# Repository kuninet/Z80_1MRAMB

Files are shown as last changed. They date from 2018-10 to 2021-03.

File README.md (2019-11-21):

# Z80 128kB メモリーボード (KZ80-1MSRAM)

- 詳しい解説は以下のwikiページをご覧ください。

https://github.com/kuninet/Z80_1MRAMB/wiki

## 概要

- SBC8080ルーズキットバスにつながる128kBバンクメモリーボードです。
  - REV1 : 16kB ROM + 16kB固定RAM + 32kB 3バンクメモリー
  - REV2 ; 上記に加えて 64kBフルRAMモード装備
  - REV3 : ROM 32kジャンパ装備。アドレスデコード改良

## 機械語モニタ+TinyBASICについて

- [SBC8080データパック](http://www.amy.hi-ho.ne.jp/officetetsu/storage/sbc8080_datapack.zip)の機械語モニタ+TinyBASICを使用する場合、使用しているRAM領域(8000h〜FFFFh)をバンク切り替えする仕様となっているためRAMアドレス等を変更する必要があります。
  - [MON-TB](MON-TB/)ディレクトリにアドレス変更等を対応したソース/ROM焼き用のHEXファイルを添付しました。
  - https://github.com/kuninet/Z80_1MRAMB/tree/master/MON-TB

## ライセンス

- 本リポジトリのデータは MIT License のもとで公開します。[LICENSE.txt](LICENSE.txt)を参照して下さい。

## 参考リンク

- [SBC8080バスにつながる128kBメモリーボード(1)](https://kuninet.org/2018/08/11/sbc8080バスにつながる128kbメモリーボード1/)
- [SBC8080バスにつながる128kBメモリーボード(2)](https://kuninet.org/2018/08/12/sbc8080バスにつながる128kbメモリーボード2/)
- [SBC8080バスにつながる128kBメモリーボード(3)](https://kuninet.org/2018/08/13/sbc8080バスにつながる128kbメモリーボード3/)
  - 【注意】上記のBLOGの試作記事ではI/Oアドレスを40hにしていますが、当基板(REV1、1.1)では80hへ変更しています。
  
- KZ80-1MSRAM Rev.1 リリース0.9
  - [https://kuninet.org/2018/10/21/kz80-1msram-rev-1-%e3%83%aa%e3%83%aa%e3%83%bc%e3%82%b90-9/](https://kuninet.wordpress.com/2018/10/21/kz80-1msram-rev-1-%e3%83%aa%e3%83%aa%e3%83%bc%e3%82%b90-9/)
- KZ80/SBC80系 128kBメモリーボード REV2
  - [https://kuninet.org/2018/12/28/kz80-sbc80%e7%b3%bb-128kb%e3%83%a1%e3%83%a2%e3%83%aa%e3%83%bc%e3%83%9c%e3%83%bc%e3%83%89-rev2/](https://kuninet.wordpress.com/2018/12/28/kz80-sbc80%e7%b3%bb-128kb%e3%83%a1%e3%83%a2%e3%83%aa%e3%83%bc%e3%83%9c%e3%83%bc%e3%83%89-rev2/)

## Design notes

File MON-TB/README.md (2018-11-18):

# 機械語モニタ+TinyBASIC　(for KZ80-1MSRAM : 128kBバンクメモリー対応)

## オリジナルソースの所在

- 本ソースは、[SBC8080データパック](http://www.amy.hi-ho.ne.jp/officetetsu/storage/sbc8080_datapack.zip)に同梱されている PTBEXSA.ASM に変更を加えたものです。

## 修正点

- ワーク用メモリー領域を 固定メモリー域アドレス(4000h〜7FFFh)へ変更

```
　　FTOP	EQU	4000H
　　LTOP	EQU	5000H
　　VTOP	EQU	07000H
　　STACK	EQU	07E00H
```
- 機械語モニタのRAM開始アドレスーを変更

```
CC1:
main:
	LXI	H,-484
	DAD	SP
	SPHL
	LXI	H,482
	DAD	SP
	XCHG;;
	LXI	H,16384     <-- 4000hへ変更
	CALL	CCPINT
```

- バンクメモリーをバンク1へ初期セット

```
	ORG	ITOP
ENTRY:
;-- BANK MEM SET
	MVI	A,01H
	OUT	80H
;
```

- おまけ : Z80割り込みモード1で動作させたい場合
  - Z80割り込みモード1(割り込みがあったら強制的にRST 38hを実行)で使用したい場合はコメントアウトを外して再コンパイルしてください。

```
;
;	SYSTEM INITIALIZE
SYSINI:
	LXI	SP,STACK
;	DB	0EDH,056H   <-- コメントアウトを外すと Z80 割り込みモード1で動作します
	MVI	A,11H
```

- 上記修正によりメモリーマップは以下のようになります。

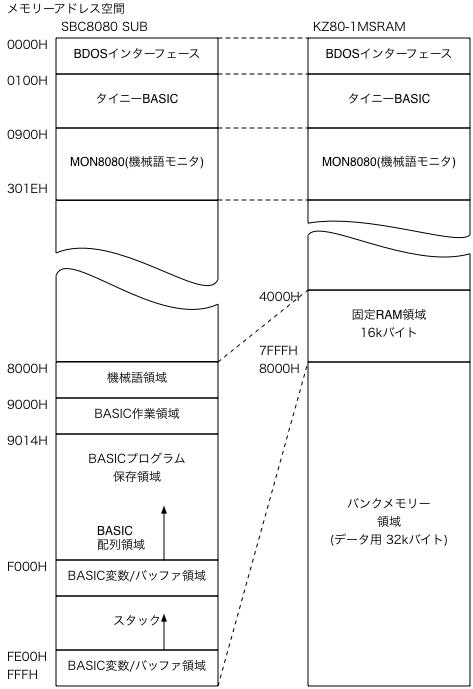
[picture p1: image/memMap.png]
メモリーマップ


## 使い方

- KZ80-1MSRAMボードで使用する場合は、HEXファイル(PTBEXS1M.HEX)を28C256(EEPROM)へ焼いてご使用ください。
- ソースを修正して再アセンブリしたい場合は、CP/MエミュレーターでMAC.COMを使ってアセンブリしてください。

  - 再アセンブリ例
```
C:\wk>\cpm32_04\cpm MAC PTBEXS1M.ASM
CP/M MACRO ASSEM 2.0
7F04
024H USE FACTOR
END OF ASSEMBLY

C:\wk>
```

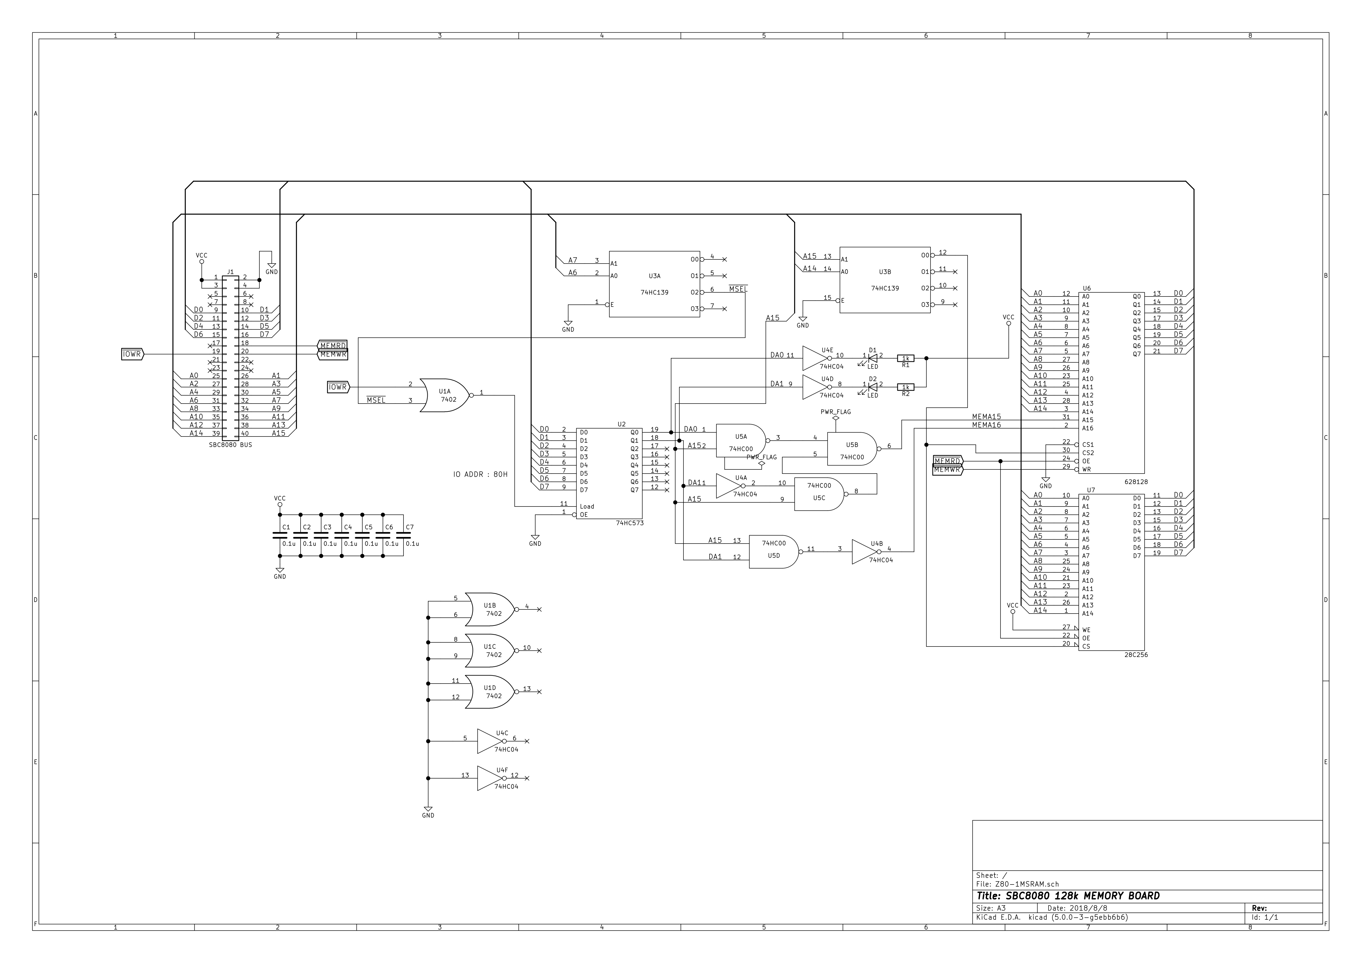
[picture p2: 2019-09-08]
image/Z80-1MSRAM-REV1.jpg

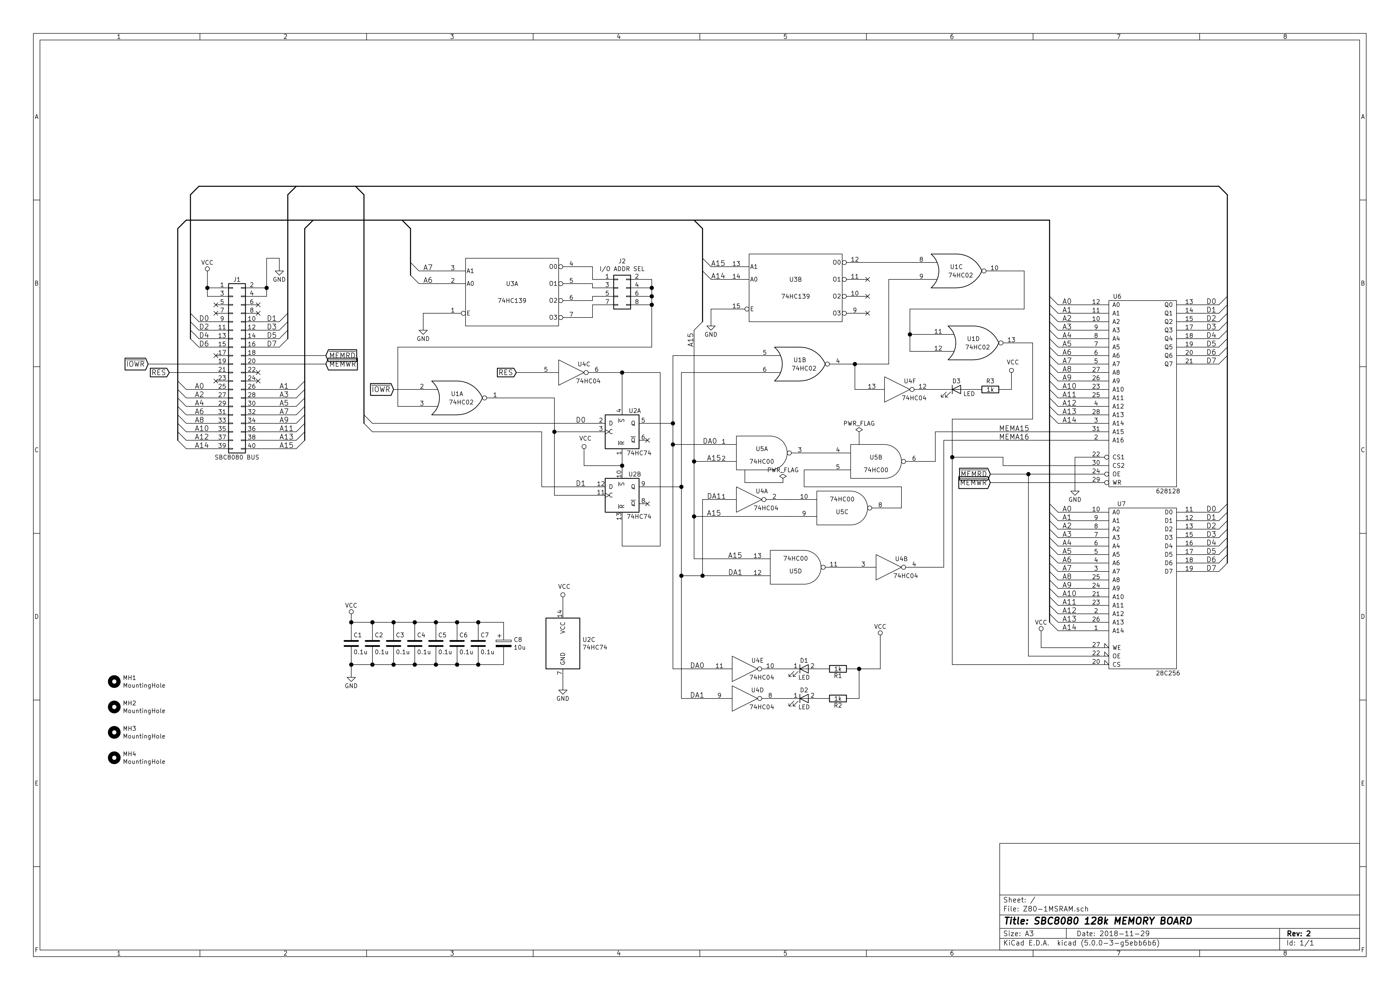
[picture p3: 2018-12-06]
image/Z80-1MSRAM-REV2.jpg

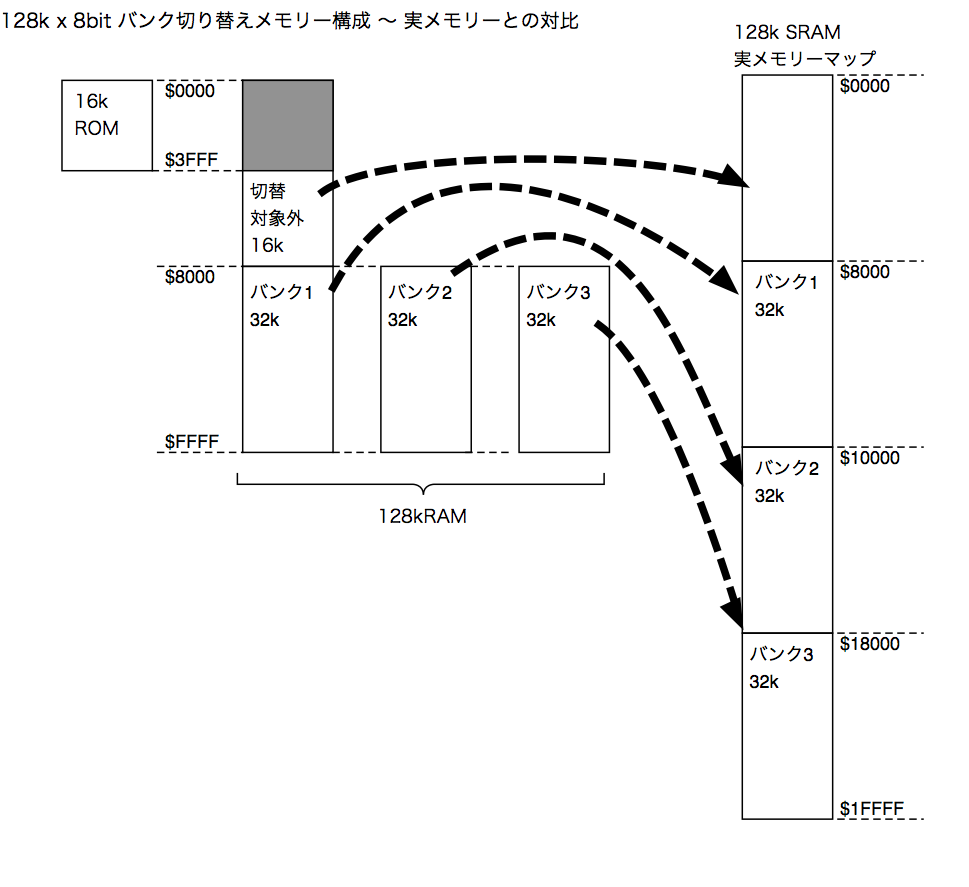
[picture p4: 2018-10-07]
image/mem-image.png

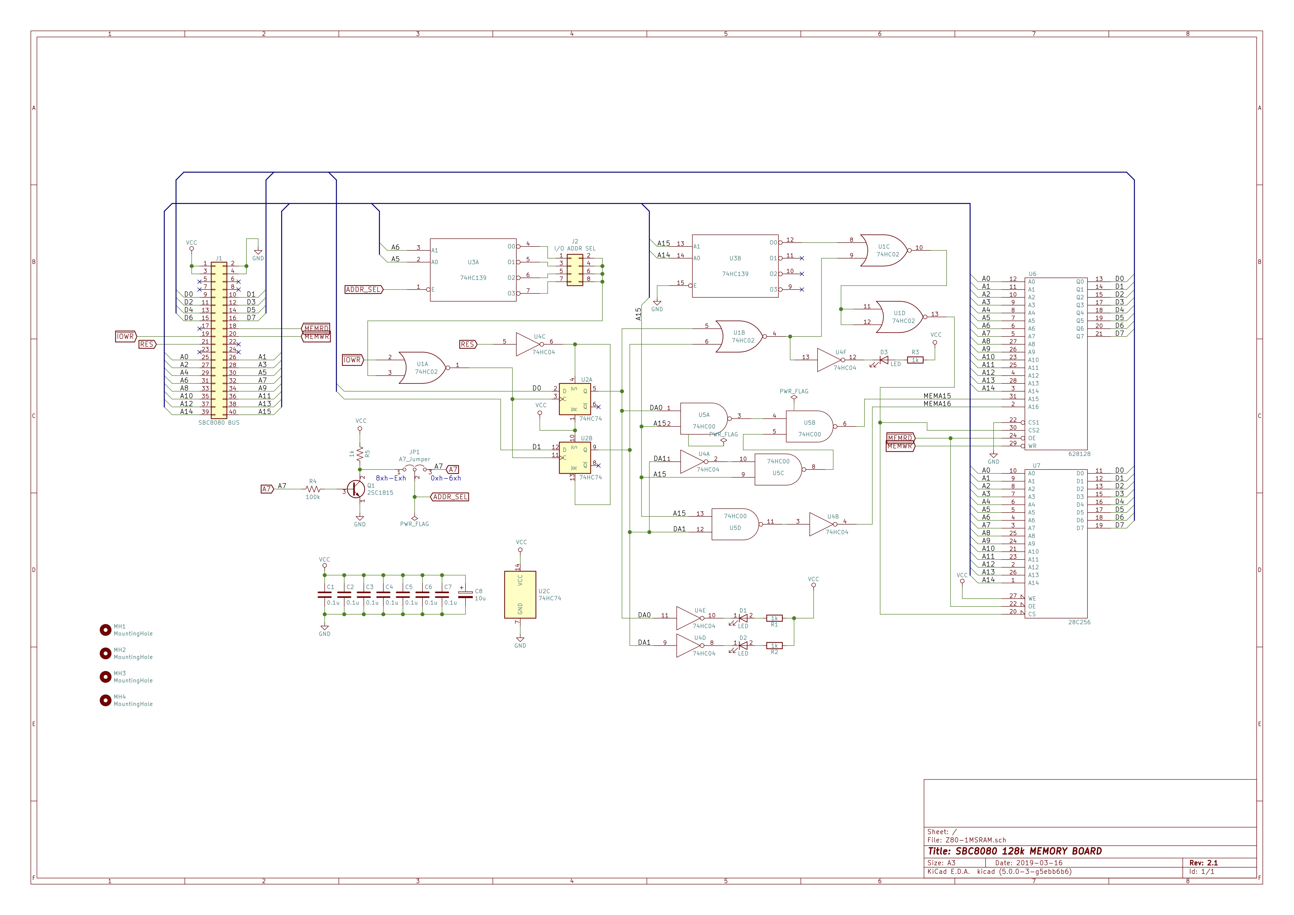
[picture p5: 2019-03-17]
image/Z80-1MSRAM-REV2-1.jpg

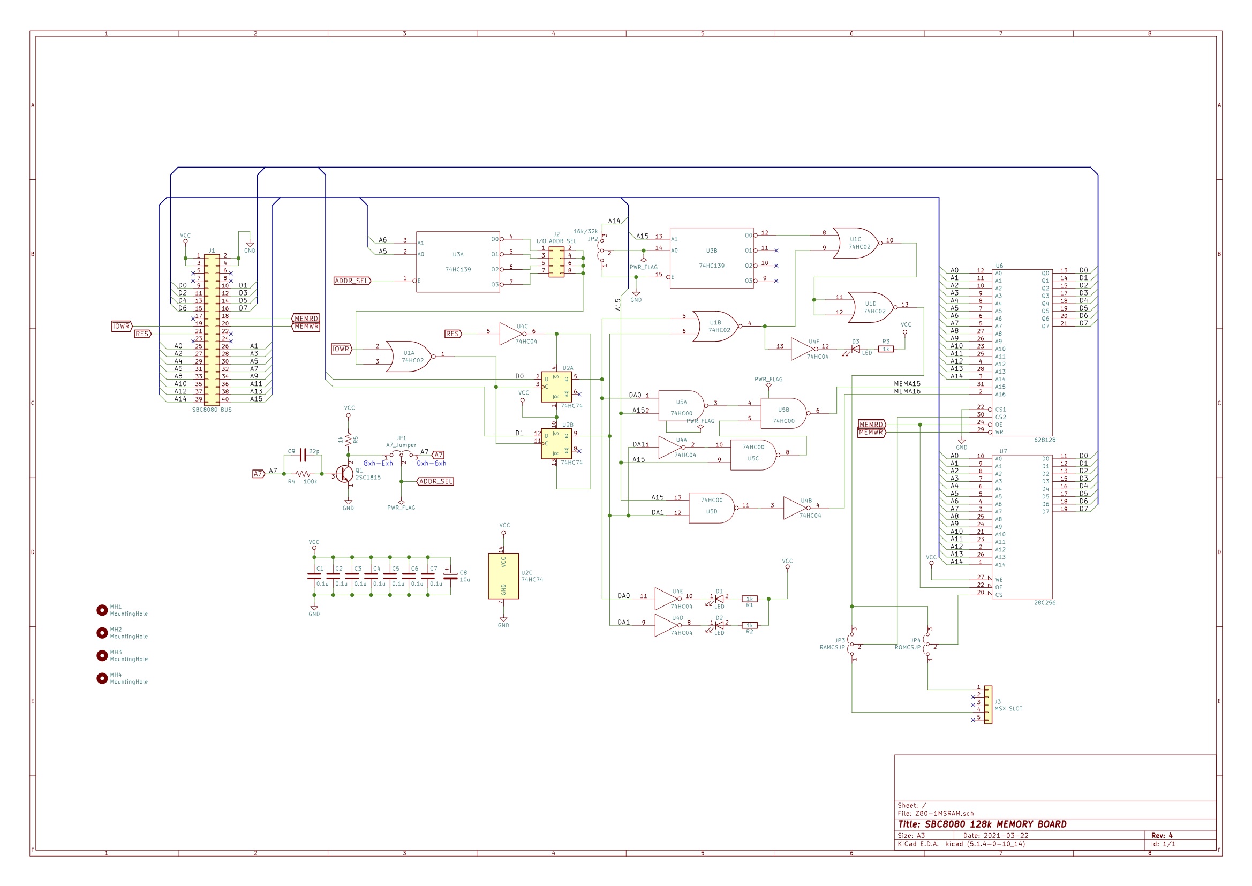
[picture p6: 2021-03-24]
image/Z80-1MSRAM-REV4.jpg

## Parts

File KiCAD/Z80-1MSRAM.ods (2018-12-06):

部品番号 | 仕様 | 数量 | 代替可能品 | 備考 | Footprint
U1 | 74HC02 | 1 | 74HCT02 |  | Housings_DIP:DIP-14_W7.62mm_Socket
U2 | 74HC74 | 1 | 74HCT74 |  | Housings_DIP:DIP-14_W7.62mm_Socket
U3 | 74HC139 | 1 | 74HCT139 |  | Housings_DIP:DIP-16_W7.62mm_Socket
U4 | 74HC04 | 1 | 74HCT04 |  | Housings_DIP:DIP-14_W7.62mm_Socket
U5 | 74HC00 | 1 | 74HCT00 |  | Housings_DIP:DIP-14_W7.62mm_Socket
U6 | HM628128ALP-7 | 1 | 128kB SRAM | ☆ピンアサインに注意。同等品を確認してください。 | Housings_DIP:DIP-32_W15.24mm_Socket
U7 | ATC28C256 | 1 | 32kB EEPROM | 16kB分のみ使用します | Housings_DIP:DIP-28_W15.24mm_Socket
D1、D2、D3 | LED | 2 | LED |  | LEDs:LED-3MM
R1、R2、R3 | 1kΩ | 2 | カーボン抵抗器 |  | Resistors_THT:R_Axial_DIN0207_L6.3mm_D2.5mm_P10.16mm_Horizontal
J1 | HIF3FC-40PA-2.54DS | 1 | 40 ピン L 型ボックスヘッダ |  | Pin_Headers:Pin_Header_Angled_2x20
C1〜C7 | 0.1uF | 7 | 積層セラミックコンデンサ |  | Capacitors_THT:C_Rect_L4.0mm_W2.5mm_P2.50mm
C8 | 10uF | 1 | 電解/タンタルコンデンサ |  | Capacitor_THT:CP_Radial_D5.0mm_P2.50mm

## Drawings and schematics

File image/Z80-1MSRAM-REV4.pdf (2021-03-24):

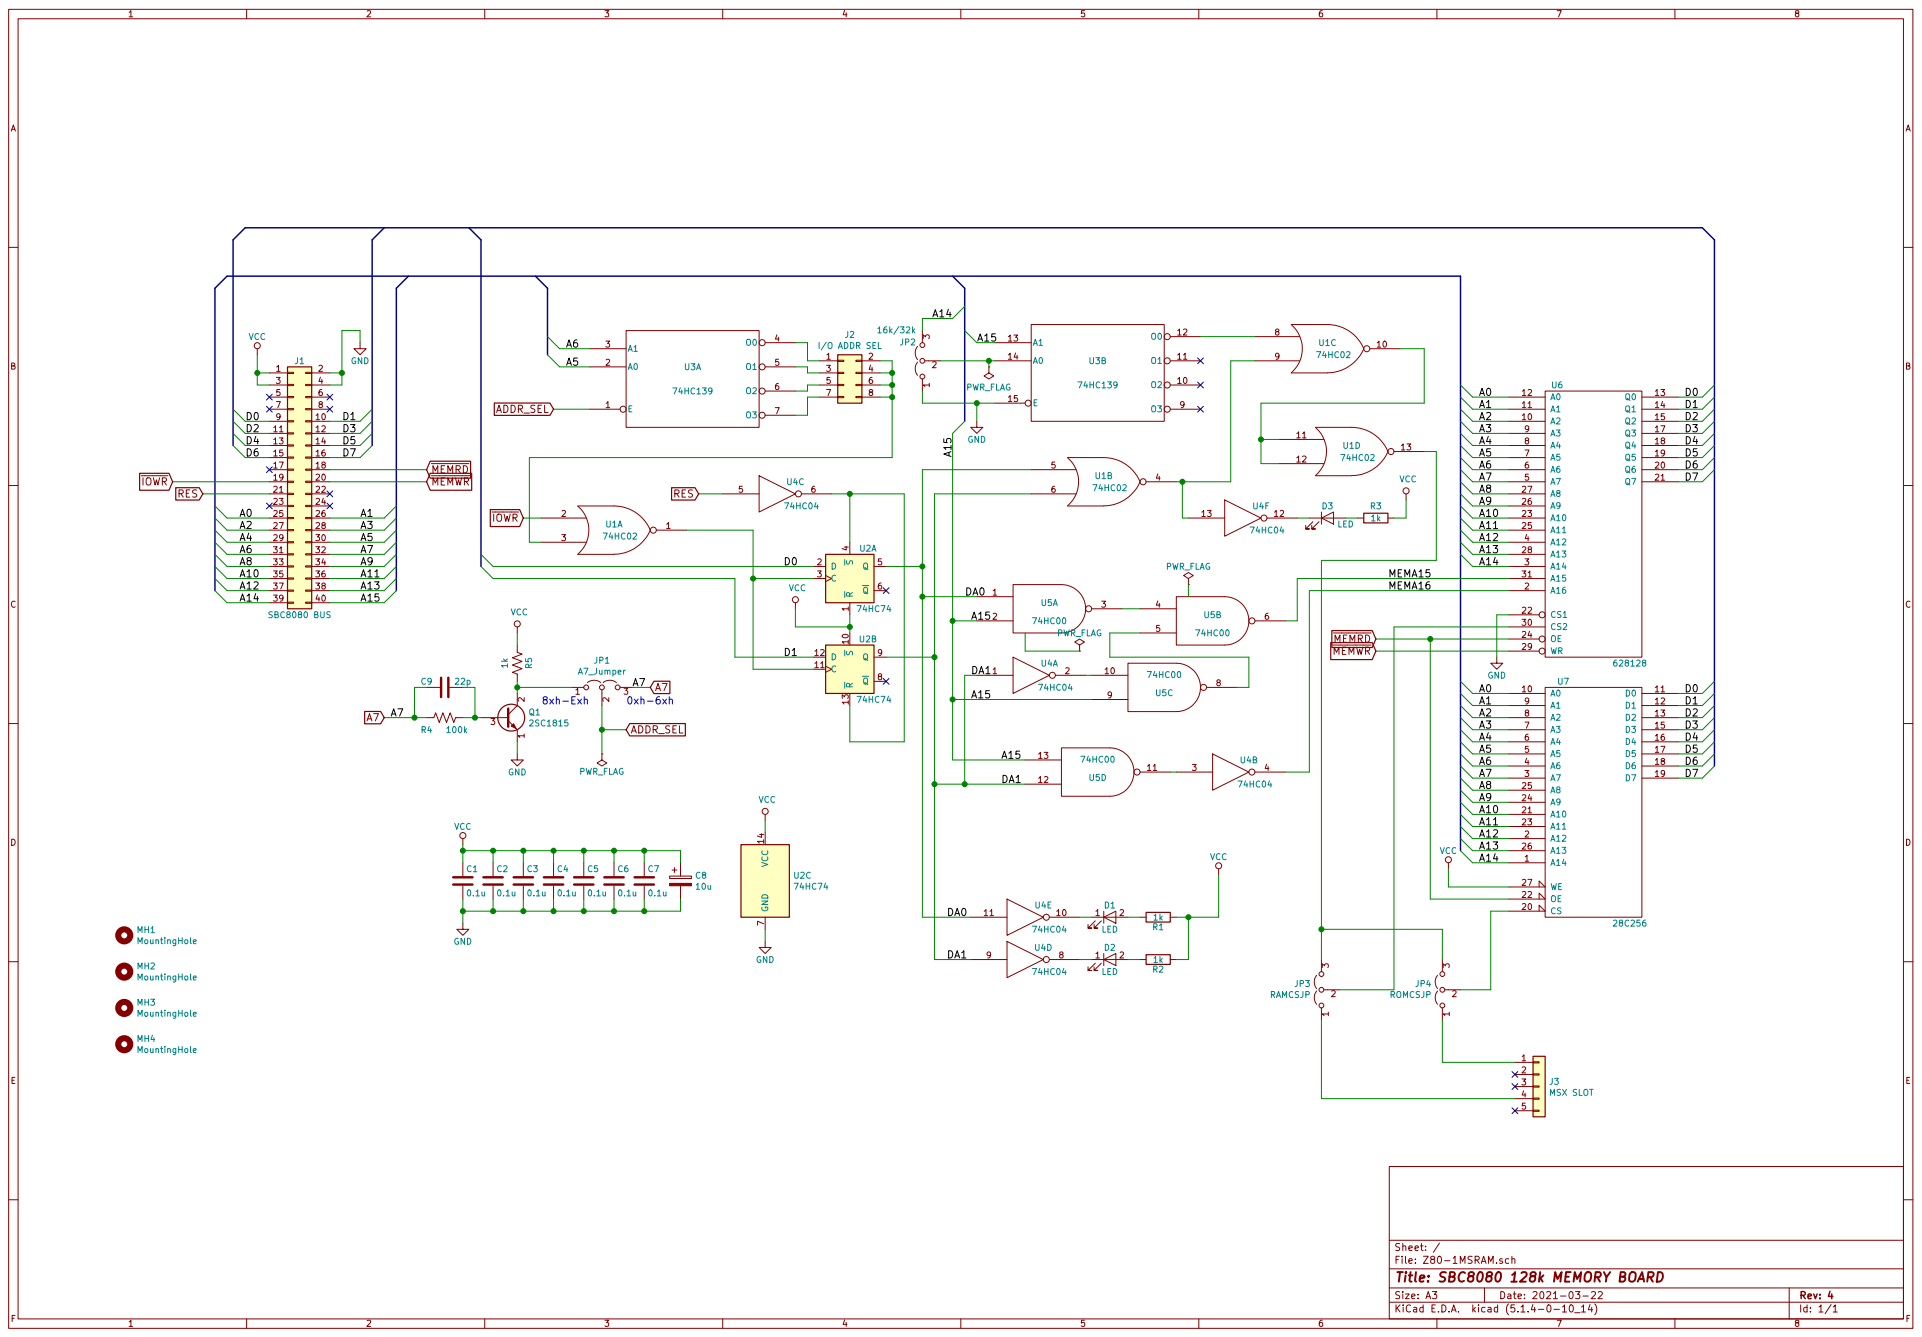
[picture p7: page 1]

File: Z80-1MSRAM.sch Sheet: / MH1 MountingHole

Id: 1/1 Title: SBC8080 128k MEMORY BOARD

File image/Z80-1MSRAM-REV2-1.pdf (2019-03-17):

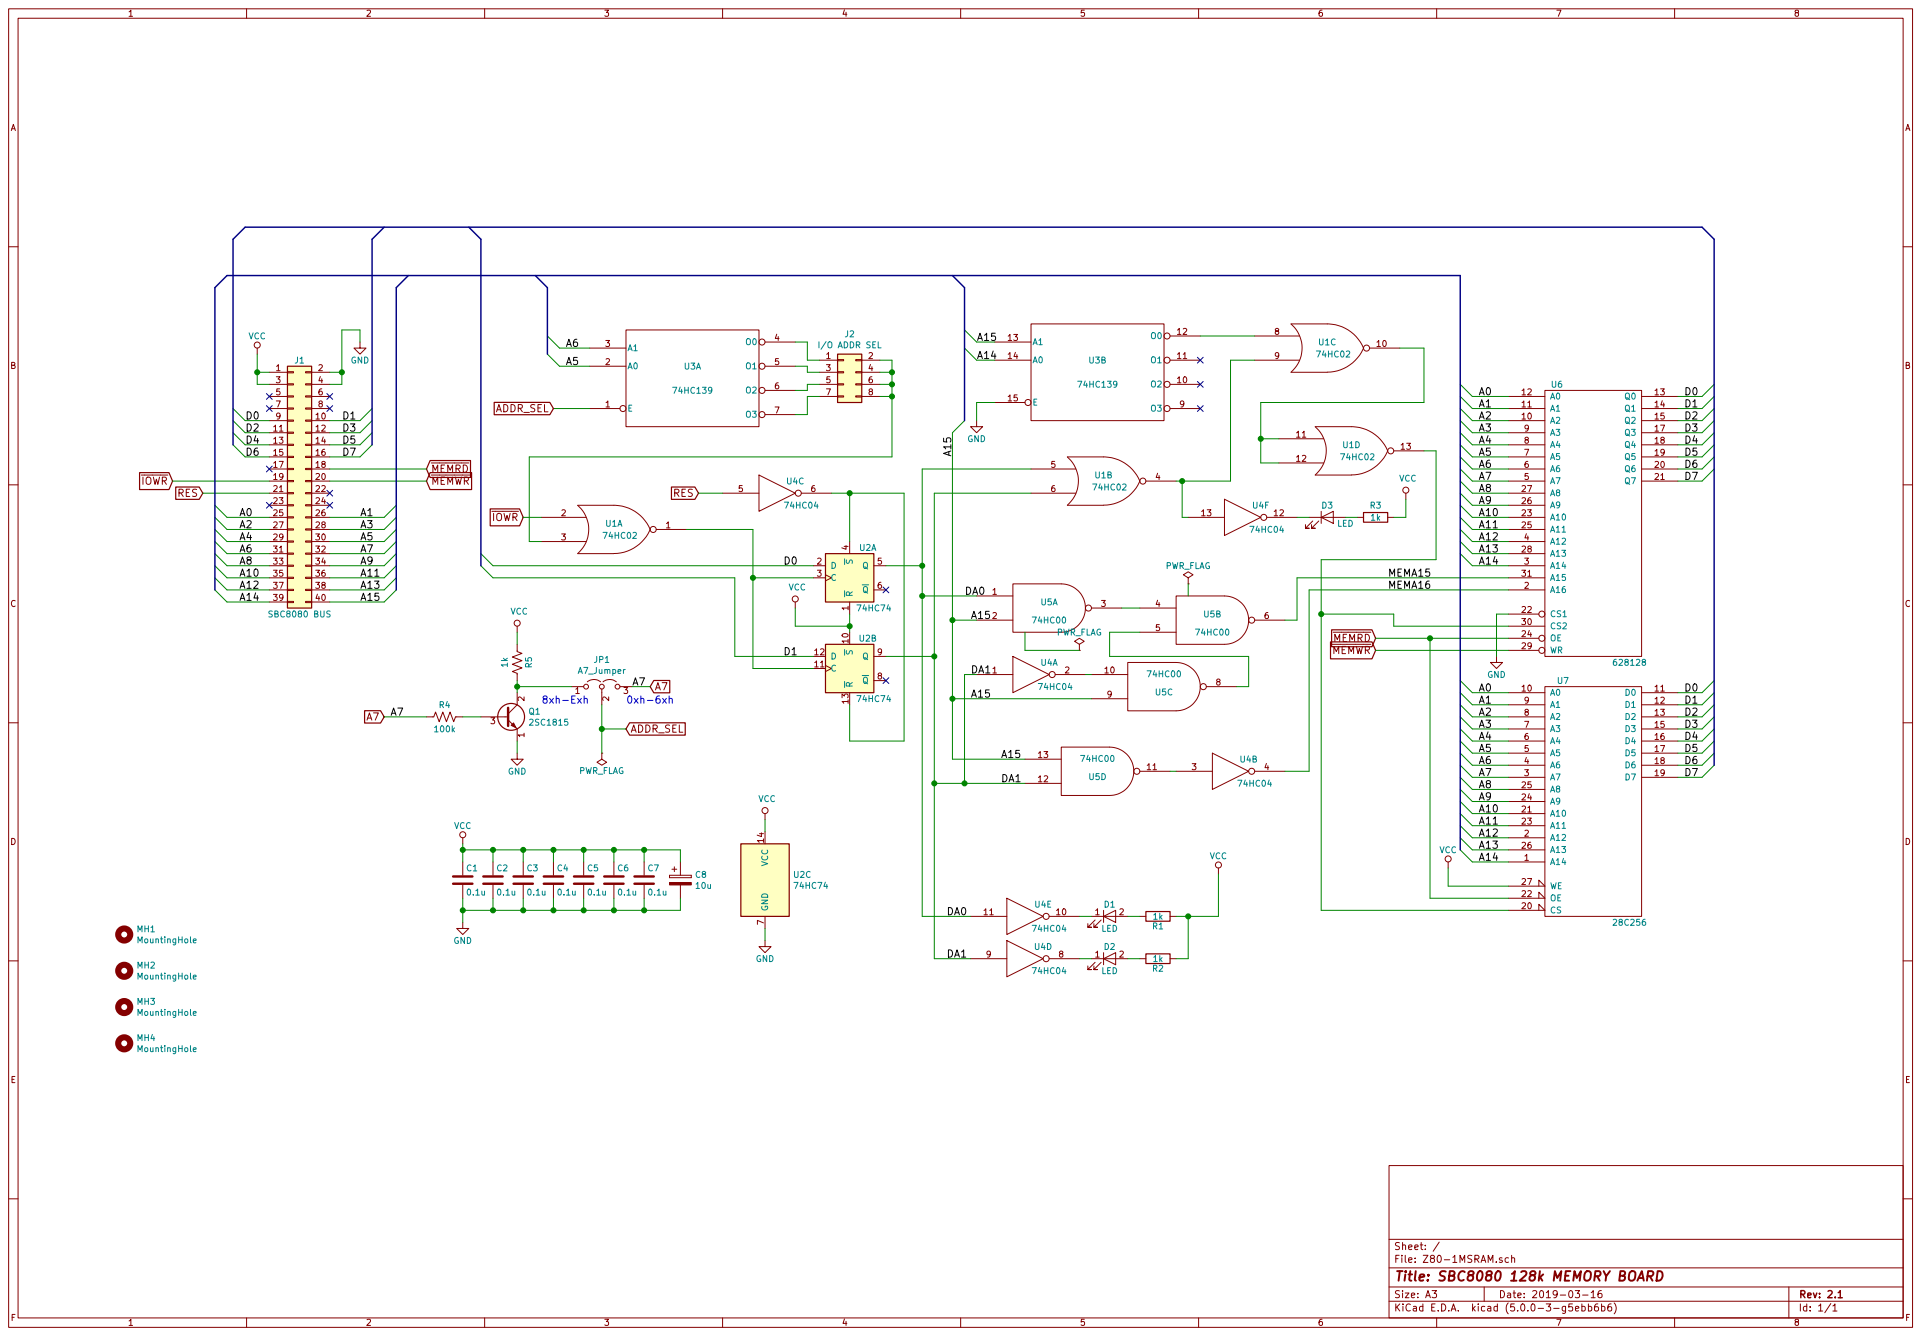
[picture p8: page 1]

10u MH1 MountingHole MH2 MountingHole MH3 MountingHole MH4 MountingHole

File: Z80-1MSRAM.sch Sheet: /
Id: 1/1 Title: SBC8080 128k MEMORY BOARD

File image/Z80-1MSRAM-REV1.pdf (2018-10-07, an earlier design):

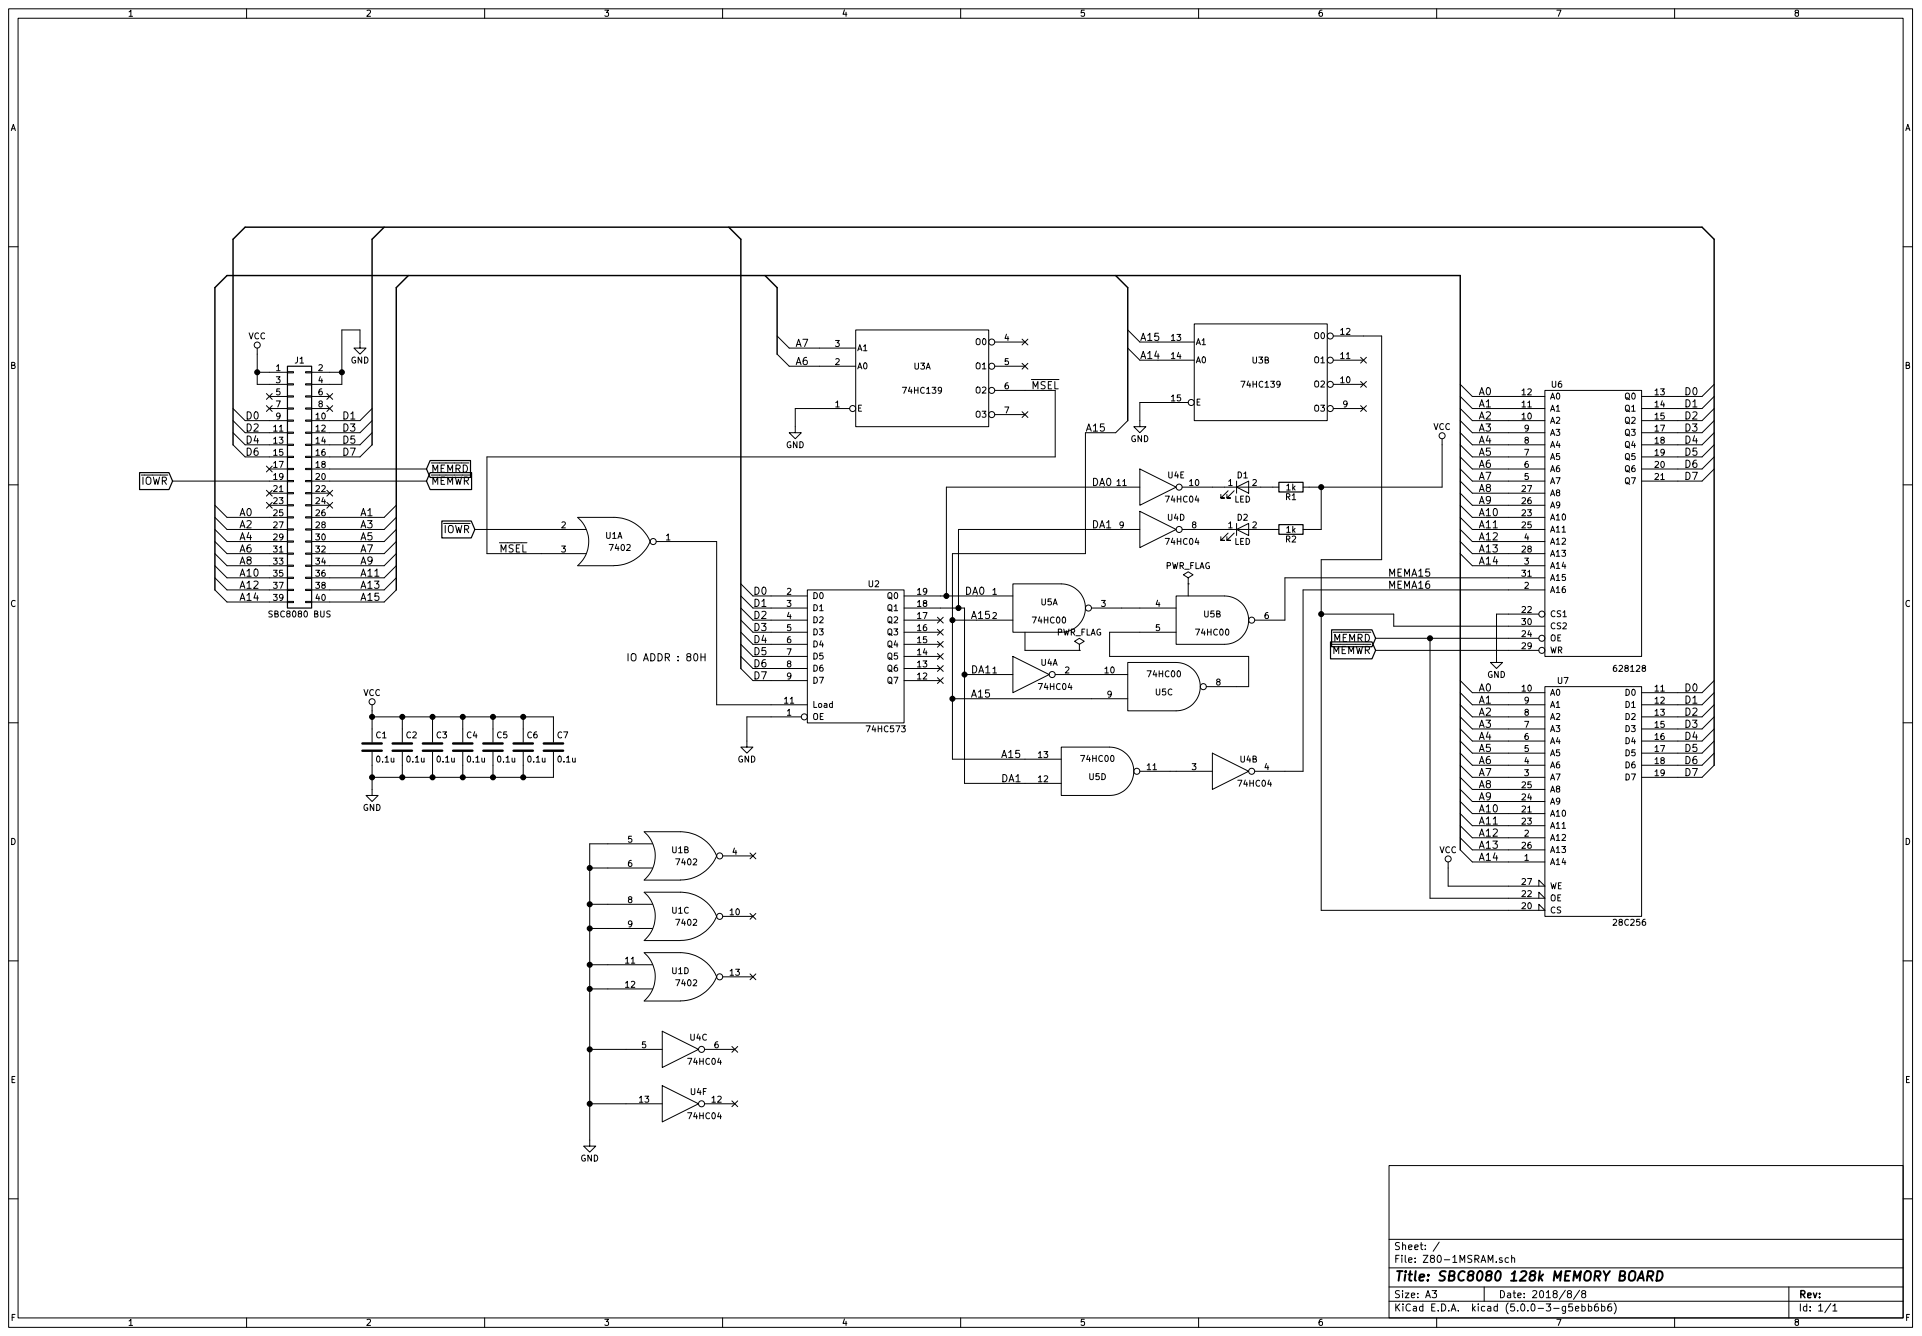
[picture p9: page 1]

File: Z80-1MSRAM.sch Sheet: /
Id: 1/1 Title: SBC8080 128k MEMORY BOARD

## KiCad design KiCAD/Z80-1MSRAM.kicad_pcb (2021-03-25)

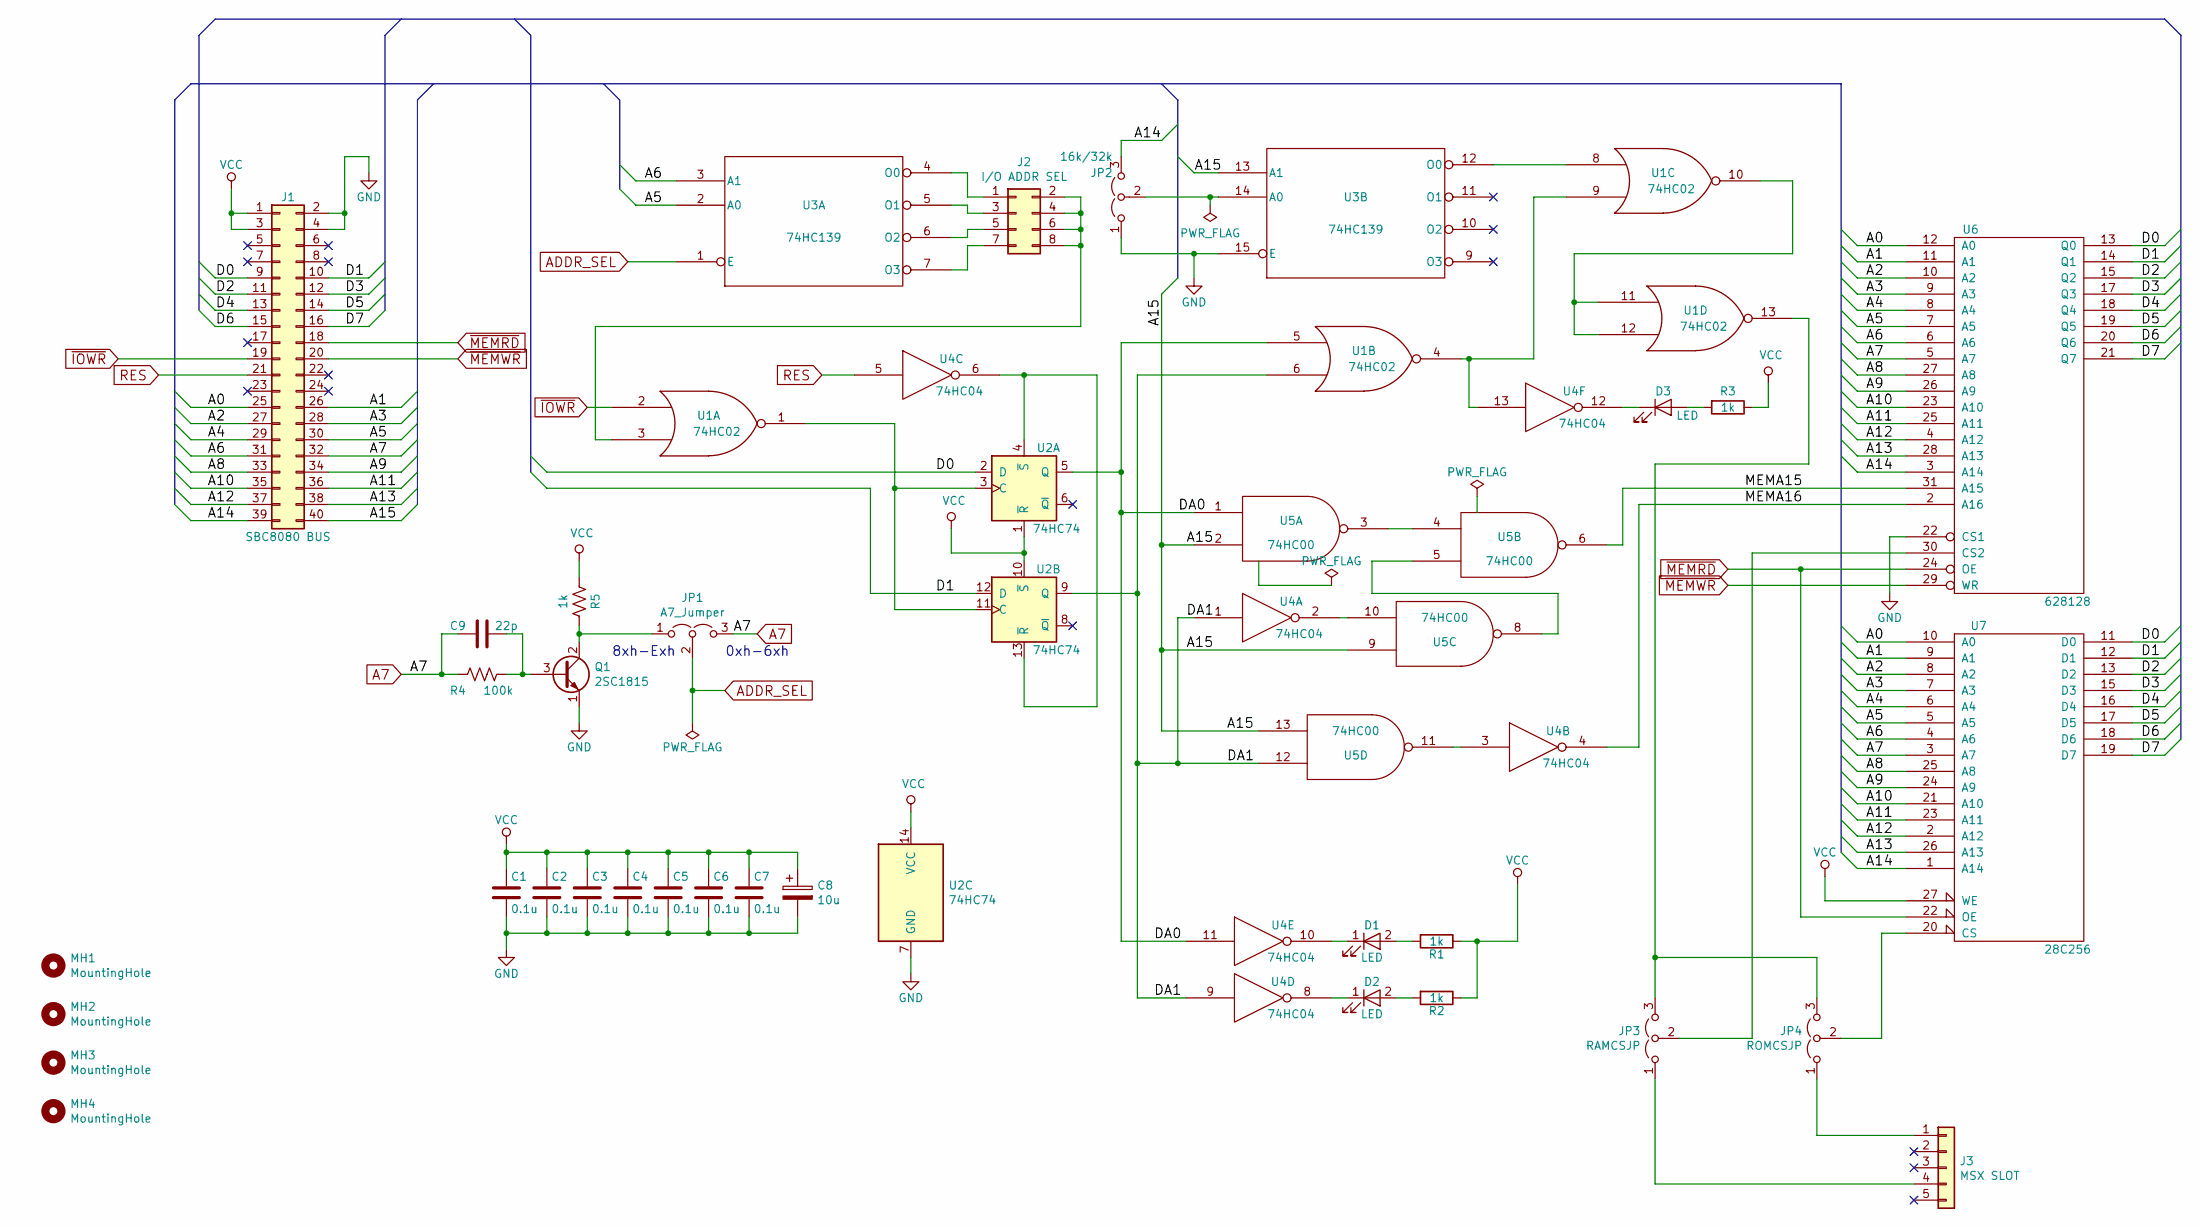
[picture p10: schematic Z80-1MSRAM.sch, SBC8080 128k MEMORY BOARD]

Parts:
C1, C2, C3, C4, C5, C6, C7: 0.1u; C_Rect_L4.0mm_W2.5mm_P2.50mm
C8: 10u; CP_Radial_D5.0mm_P2.50mm
C9: 22p; C_Disc_D3.0mm_W1.6mm_P2.50mm
D1, D2: LED; LED-3MM
D3: LED; LED_D3.0mm
J1: SBC8080 BUS; Pin_Header_Angled_2x20
J2: I/O ADDR SEL; PinHeader_2x04_P2.54mm_Vertical
J3: MSX SLOT; PinHeader_1x05_P2.54mm_Vertical
JP1: A7_Jumper; PinHeader_1x03_P2.54mm_Vertical
JP2: 16k/32k; PinHeader_1x03_P2.54mm_Vertical
JP3: RAMCSJP; PinHeader_1x03_P2.54mm_Vertical
JP4: ROMCSJP; PinHeader_1x03_P2.54mm_Vertical
MH1, MH2, MH3, MH4: MountingHole; MountingHole_3.2mm_M3
Q1: 2SC1815; TO-92L_Inline_Wide
R1, R2, R3, R5: 1k; R_Axial_DIN0207_L6.3mm_D2.5mm_P10.16mm_Horizontal
R4: 100k; R_Axial_DIN0207_L6.3mm_D2.5mm_P10.16mm_Horizontal
U1: 74HC02; DIP-14_W7.62mm_Socket
U2: 74HC74; DIP-14_W7.62mm_Socket
U3: 74HC139; DIP-16_W7.62mm_Socket
U4: 74HC04; DIP-14_W7.62mm_Socket
U5: 74HC00; DIP-14_W7.62mm_Socket
U6: 628128; DIP-32_W15.24mm_Socket
U7: 28C256; DIP-28_W15.24mm_Socket

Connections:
/A0: J1.25, U6.12 (A0), U7.10 (A0)
/A1: J1.26, U6.11 (A1), U7.9 (A1)
/A2: J1.27, U6.10 (A2), U7.8 (A2)
/A3: J1.28, U6.9 (A3), U7.7 (A3)
/A4: J1.29, U6.8 (A4), U7.6 (A4)
/A5: J1.30, U3.2 (A0), U6.7 (A5), U7.5 (A5)
/A6: J1.31, U3.3 (A1), U6.6 (A6), U7.4 (A6)
/A8: J1.33, U6.27 (A8), U7.25 (A8)
/A9: J1.34, U6.26 (A9), U7.24 (A9)
/A10: J1.35, U6.23 (A10), U7.21 (A10)
/A11: J1.36, U6.25 (A11), U7.23 (A11)
/A12: J1.37, U6.4 (A12), U7.2 (A12)
/A13: J1.38, U6.28 (A13), U7.26 (A13)
/A14: J1.39, JP2.3 (B), U6.3 (A14), U7.1 (A14)
/A15: J1.40, U3.13 (A1), U5.2, U5.9, U5.13
/D0: J1.9, U2.2 (D), U6.13 (Q0), U7.11 (D0)
/D1: J1.10, U2.12 (D), U6.14 (Q1), U7.12 (D1)
/D2: J1.11, U6.15 (Q2), U7.13 (D2)
/D3: J1.12, U6.17 (Q3), U7.15 (D3)
/D4: J1.13, U6.18 (Q4), U7.16 (D4)
/D5: J1.14, U6.19 (Q5), U7.17 (D5)
/D6: J1.15, U6.20 (Q6), U7.18 (D6)
/D7: J1.16, U6.21 (Q7), U7.19 (D7)
/DA0: U1.5, U2.5 (Q), U4.11, U5.1
/DA1: U1.6, U2.9 (Q), U4.1, U4.9, U5.12
/MEMA15: U5.6, U6.31 (A15)
/MEMA16: U4.4, U6.2 (A16)
A7: C9.2, J1.32, JP1.3 (B), R4.2, U6.5 (A7), U7.3 (A7)
ADDR_SEL: JP1.2 (C), U3.1 (E)
GND: C1.2, C2.2, C3.2, C4.2, C5.2, C6.2, C7.2, C8.2, J1.2, J1.4, JP2.1 (A), Q1.1 (E), U1.7 (GND), U2.7 (GND), U3.8 (GND), U3.15 (E), U4.7 (GND), U5.7 (GND), U6.16 (GND), U6.22 (CS1), U7.14 (GND)
unnamed: C9.1, Q1.3 (B), R4.1
unnamed: D1.1 (K), U4.10
unnamed: D1.2 (A), R1.2
unnamed: D2.1 (K), U4.8
unnamed: D2.2 (A), R2.2
unnamed: D3.1 (K), U4.12
unnamed: D3.2 (A), R3.2
unnamed: J2.1, U3.4 (O0)
unnamed: J2.2, J2.4, J2.6, J2.8, U1.3
unnamed: J2.3, U3.5 (O1)
unnamed: J2.5, U3.6 (O2)
unnamed: J2.7, U3.7 (O3)
unnamed: J3.1, JP4.1 (A)
unnamed: J3.4, JP3.1 (A)
unnamed: JP1.1 (A), Q1.2 (C), R5.1
unnamed: JP2.2 (C), U3.14 (A0)
unnamed: JP3.2 (C), U6.30 (CS2)
unnamed: JP3.3 (B), JP4.3 (B), U1.13
unnamed: JP4.2 (C), U7.20 (CS)
unnamed: U1.1, U2.3 (C), U2.11 (C)
unnamed: U1.4, U1.9, U4.13
unnamed: U1.8, U3.12 (O0)
unnamed: U1.10, U1.11, U1.12
unnamed: U2.4 (~S), U2.13 (~R), U4.6
unnamed: U4.2, U5.10
unnamed: U4.3, U5.11
unnamed: U5.3, U5.4
unnamed: U5.5, U5.8
RES: J1.21, U4.5
VCC: C1.1, C2.1, C3.1, C4.1, C5.1, C6.1, C7.1, C8.1, J1.1, J1.3, R1.1, R2.1, R3.1, R5.2, U1.14 (VCC), U2.1 (~R), U2.10 (~S), U2.14 (VCC), U3.16 (VCC), U4.14 (VCC), U5.14 (VCC), U6.32 (VCC), U7.27 (WE), U7.28 (VCC)
~IOWR: J1.19, U1.2
~MEMRD: J1.18, U6.24 (OE), U7.22 (OE)
~MEMWR: J1.20, U6.29 (WR)

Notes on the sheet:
0xh-6xh
8xh-Exh

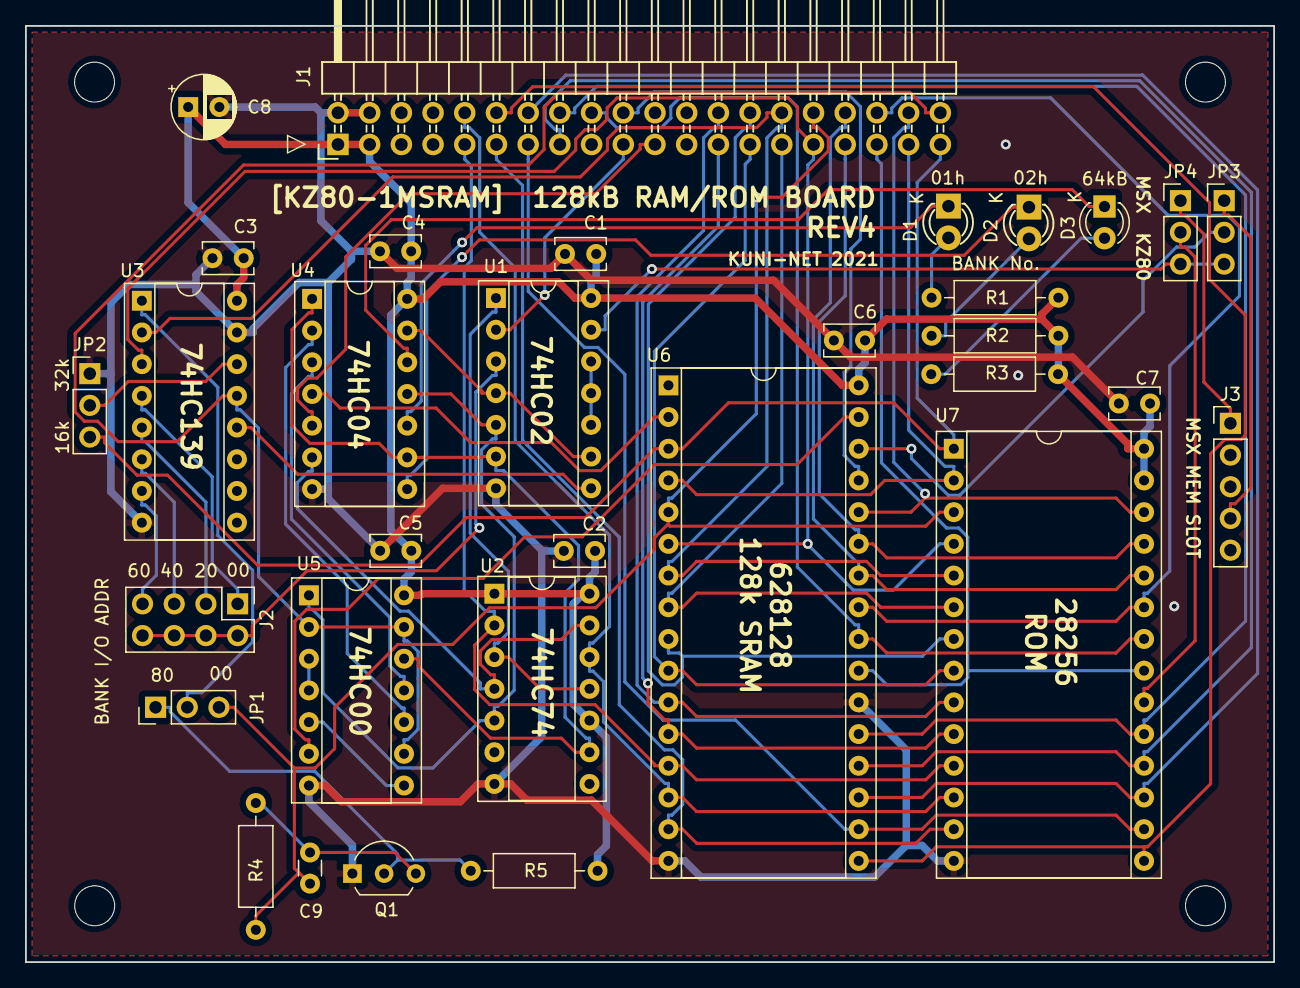
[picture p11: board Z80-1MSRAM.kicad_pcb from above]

Board: 2 copper layers, 100.0 x 75.0 mm, 36 parts (0 on the bottom side), 63 nets.

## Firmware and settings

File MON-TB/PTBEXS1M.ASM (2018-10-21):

; Small-C Version 3.01  90/06/01  < FUTURE FORUM & S.Kiyo > 
; modify for 128kRAM (KZ80-1MSRAM)
; 
ITOP	EQU	0100H
FTOP	EQU	4000H
LTOP	EQU	5000H
VTOP	EQU	07000H
STACK	EQU	07E00H
;
LBUF	EQU	VTOP+0037H
LBFSZ	EQU	80
MSTK	EQU	LBUF+LBFSZ
TMSTK	EQU	MSTK+30
;
PROMPT	EQU	'>'
RUBOUT	EQU	7FH
BS	EQU	08H
ESC	EQU	1BH
;
TST	MACRO	STR,ADRS
	CALL	TEST
	DB	STR
	DB	ADRS-$-1
	ENDM
CASE	MACRO	STR,ADRS
	DB	STR
	DB	(ADRS SHR 8)+80H
	DB	ADRS AND 0FFH
	ENDM
ENDC	MACRO	ADRS
	DB	(ADRS+8000H) SHR 8
	DB	ADRS AND 0FFH
	ENDM
;
UARTRD	EQU	00H
UARTRC	EQU	01H
;
;	BDOS VERSION 1.03
;
;
;	RESET
	ORG	0000H
	JMP	SYSINI
;
;	BDOS
	ORG	0005H
BDOS:
	PUSH	PSW
	MOV	A,C
	RLC
	ADD	C
	MOV	C,A
	POP	PSW
	MVI	B,00H
	LXI	H,JMPTBL
	DAD	B
	PCHL
JMPTBL:	JMP	SYSINI
	JMP	RBUFRD
	JMP	USRTWT
	JMP	RBUFRD
	JMP	USRTWT
	JMP	USRTWT
	JMP	DCONIO
;
;	8251 -> A
USRTRD:
	IN	UARTRC
	ANI	00000010B
	JZ	USRTRD
	IN	UARTRD
	RET
;
;	RST7
	ORG	0038H
INTRCV:
	DI
	PUSH	PSW
	PUSH	B
	PUSH	D
	PUSH	H
	CALL	USRTRD
	CPI	11H
	JZ	STRWT1
	CPI	13H
	JNZ	STRWT2
STRWT1:	STA	XFLAGS
	JMP	RWTEXT
STRWT2:	MOV	D,A
	LDA	RBFCNT
	CPI	0FFH
	JZ	RWTEXT
	CPI	0FFH-80
	JNZ	STRWT3
	MVI	E,13H
	CALL	USRTWT
STRWT3:	INR	A
	STA	RBFCNT
	LDA	RBFWTP
	MOV	C,A
	MVI	B,00H
	LXI	H,RECBUF
	DAD	B
	MOV	M,D
	INR	A
	STA	RBFWTP
RWTEXT:	POP	H
	POP	D
	POP	B
	POP	PSW
	EI
	RET
;
;	BUFER -> A
RBUFRD:
	PUSH	B
	PUSH	D
	PUSH	H
LOPRBR:	LDA	RBFCNT
	CPI	00H
	JZ	LOPRBR
	DI
	CPI	0FFH-80
	JNZ	STRRD1
	MVI	E,11H
	CALL	USRTWT
STRRD1:	DCR	A
	STA	RBFCNT
	LDA	RBFRDP
	MOV	C,A
	MVI	B,00H
	LXI	H,RECBUF
	DAD	B
	MOV	D,M
	INR	A
	STA	RBFRDP
	MOV	A,D
	EI
	POP	H
	POP	D
	POP	B
	RET
;
;	E -> 8251
USRTWT:
	PUSH	PSW
UWLOP1:	LDA	XFLAGS
	CPI	13H
	JZ	UWLOP1
UWLOP2:	IN	UARTRC
	ANI	00000001B
	JZ	UWLOP2
	MOV	A,E
	OUT	UARTRD
	POP	PSW
	RET
;
;	DIRECT I/O
DCONIO:
	PUSH	PSW
	MOV	A,E
	CPI	0FFH
	JZ	DCONIN
	JMP	UWLOP2
DCONIN:	POP	PSW
	LDA	RBFCNT
	CPI	00H
	RZ
	JMP	RBUFRD
;
;	SYSTEM INITIALIZE
SYSINI:
	LXI	SP,STACK
;	DB	0EDH,056H
	MVI	A,11H
	STA	XFLAGS
	MVI	A,00H
	STA	RBFCNT
	STA	RBFRDP
	STA	RBFWTP
	OUT	UARTRC
	OUT	UARTRC
	OUT	UARTRC
	MVI	A,01000000B
	OUT	UARTRC
	MVI	A,01001110B
	OUT	UARTRC
	MVI	A,00110111B
	OUT	UARTRC
;
	EI
;
	JMP	ENTRY
;
	ORG	ITOP
ENTRY:
;-- BANK MEM SET
	MVI	A,01H
	OUT	80H
;
	LXI	SP,STACK
	LXI	H,OTOP
	SHLD	OBTM
	CALL	CRLF
	LXI	D,OPNMS1
	SUB	A
	CALL	MSG
	LXI	D,OPNMS2
	SUB	A
	CALL	MSG
	LXI	D,OPNMS3
	SUB	A
	CALL	MSG
;
START:
	CALL	CRLF
	LXI	D,OKMES
	SUB	A
	CALL	MSG
	LXI	H,$+7
	SHLD	CLABL
	LXI	H,0000H
	SHLD	FCNTR
	SHLD	RSTCK
;
EDITR:	MVI	A,PROMPT
	CALL	GETL
	PUSH	D
	LXI	D,LBUF
	CALL	GINT
	CALL	SKPBL
	MOV	A,H
	ORA	L
	POP	B
	JZ	KWCPR
INSRT:	DCX	D
	MOV	A,H
	STAX	D
	DCX	D
	MOV	A,L
	STAX	D
	PUSH	B
	PUSH	D
	MOV	A,C
	SUB	E
	PUSH	PSW
	CALL	SRCH
	PUSH	D
	JNZ	MOVE
	PUSH	D
	CALL	SKIPL
	POP	B
	LHLD	OBTM
	CALL	TRNSF
	MOV	H,B
	MOV	L,C
	SHLD	OBTM
MOVE:	POP	B
	LHLD	OBTM
	POP	PSW
	PUSH	H
	CPI	03H
	JZ	START
	ADD	L
	MOV	L,A
	MVI	A,00H
	ADC	H
	MOV	H,A
	LXI	D,VTOP
	CALL	COMPR
	JNC	ERSRY
	SHLD	OBTM
	POP	D
	CALL	TR2
	POP	D
	POP	H
	CALL	TRNSF
	JMP	EDITR
;
GETL:	CALL	PUT
	LXI	D,LBUF
GETL1:	CALL	GET
	JZ	GETL1
	CPI	0AH
	JZ	GETL1
	ORA	A
	JZ	GETL1
	CPI	BS
	JZ	CRUB
	CPI	'X'-'@'
	JZ	CCAN
	CALL	PUT
	STAX	D
	INX	D
	CPI	0DH
	RZ
	MOV	A,E
	CPI	LBUFL + LBFSZ
	JNZ	GETL1
CRUB:	MOV	A,E
	CPI	LBUFL
	JZ	GETL1
	DCX	D
	MVI	A,BS
	CALL	PUT
	JMP	GETL1
CCAN:	CALL	CRLF
	MVI	A,'@'
	JMP	GETL
LBUFL	EQU	LBUF AND 0FFH
;
SRCH:	MOV	A,H
	ORA	A
	JM	ERHOW
	LXI	D,OTOP
SRCH1:	PUSH	H
	LHLD	OBTM
	DCX	H
	CALL	COMPR
	POP	H
	RC
	LDAX	D
	SUB	L
	MOV	B,A
	INX	D
	LDAX	D
	SBB	H
	JC	SKPL1
	DCX	D
	ORA	B
	RET
;
SKIPL:	INX	D
SKPL1:	INX	D
SKPL2:	LDAX	D
	CPI	0DH
	JNZ	SKPL1
	INX	D
	JMP	SRCH1
;
TRNSF:	CALL	COMPR
	RZ
	LDAX	D
	STAX	B
	INX	D
	INX	B
	JMP	TRNSF
;
TR2:	MOV	A,B
	SUB	D
	JNZ	TR2E
	MOV	A,C
	SUB	E
	RZ
TR2E:	DCX	D
	DCX	H
	LDAX	D
	MOV	M,A
	JMP	TR2
;
KWCPR:	LXI	H,CMDKW-1
;
NXTKW:	CALL	SKPBL
NXTK1:	PUSH	D
KWC1:	LDAX	D
	INX	D
	CPI	'.'
	JZ	KWSRT
	INX	H
	CMP	M
	JZ	KWC1
	MVI	A,7FH
	DCX	D
	CMP	M
	JC	EXEQT
KWSK1:	INX	H
	CMP	M
	JNC	KWSK1
	INX	H
	POP	D
	JMP	NXTK1
;
KWSRT:	MVI	A,7FH
KWSK2:	INX	H
	CMP	M
	JNC	KWSK2
;
EXEQT:	MOV	A,M
	INX	H
	MOV	L,M
	ANI	7FH
	MOV	H,A
	POP	PSW
	PCHL
;
TEST:	XTHL
	CALL	SKPBL
	CMP	M
	INX	H
	JZ	TSTEQ
	PUSH	B
	MOV	C,M
	MVI	B,00H
	DAD	B
	POP	B
	DCX	D
TSTEQ:	INX	D
	INX	H
	XTHL
	RET
;
SKPBL:	LDAX	D
	CPI	' '
	RNZ
	INX	D
	JMP	SKPBL
;
CMDKW:	CASE	'LIST',LIST
	CASE	'RUN',RUN
	CASE	'NEW',NEW
	CASE	'SYSTEM',SSYSTEM
	CASE	'MON',MON
STMKW:	CASE	'NEXT',NEXT
	CASE	'LET',LET
	CASE	'INPUT',INPUT
	CASE	'IF',IFSTM
	CASE	'GOTO',GOTO
	CASE	'GOSUB',GOSUB
	CASE	'RETURN',RETRN
	CASE	'REM',REM
	CASE	'FOR',FOR
	CASE	'PRINT',PRINT
	CASE	'STOP',STOP
	CASE	'EXEC',SEXEC
	ENDC	LETDF
;
MON:	JMP	main
;
SEXEC:
	CALL	EEXPR
	PUSH	PSW
	PUSH	B
	PUSH	D
	LXI	D,EXRET
	PUSH	D
	LXI	D,FTOP
	DAD	D
	PCHL
EXRET:	POP	D
	POP	B
	POP	PSW
	JMP	ENDL
;
NEW:	CALL	TSCR2
	LXI	H,OTOP
	SHLD	OBTM
STOP:	CALL	TSCR2
	JMP	START
SSYSTEM:
	MVI	C,0
	CALL	0005H
;
GOSUB:	CALL	PSHV
	CALL	EEXPR
	PUSH	D
	CALL	SRCH
	JNZ	ERHW1
	LHLD	CLABL
	PUSH	H
	LHLD	RSTCK
	PUSH	H
	LXI	H,0000H
	SHLD	FCNTR
	DAD	SP
	SHLD	RSTCK
	JMP	RUN2
;
RETRN:	CALL	TSCR2
	LHLD	RSTCK
	MOV	A,H
	ORA	L
	JZ	ERWHT
	SPHL
	POP	H
	SHLD	RSTCK
	POP	H
	SHLD	CLABL
	POP	D
	CALL	POPV
	JMP	ENDL
;
FOR:	CALL	PSHV
	CALL	LTSUB
	DCX	H
	SHLD	FCNTR
	LXI	H,KWTO-1
	JMP	NXTKW
KWTO:	CASE	'TO',FORTO
	ENDC	ERWHT
;
FORTO:	CALL	EEXPR
	SHLD	FTOV
	LXI	H,KWSTP-1
	JMP	NXTKW
KWSTP:	CASE	'STEP',FSTEP
	ENDC	FSTP1
;
FSTEP:	CALL	EEXPR
	JMP	FOR0
FSTP1:	LXI	H,0001H
FOR0:	SHLD	FSTPV
	LHLD	CLABL
	SHLD	FLABL
	XCHG
	SHLD	FOBJ
	LXI	B,000AH
	LHLD	FCNTR
	XCHG
	MOV	H,B
	MOV	L,B
	DAD	SP
	DB	3EH
FOR3:	DAD	B
	MOV	A,M
	INX	H
	ORA	M
	JZ	FOR10
	MOV	A,M
	DCX	H
	CMP	D
	JNZ	FOR3
	MOV	A,M
	CMP	E
	JNZ	FOR3
FOR5:	XCHG
	LXI	H,0000H
	DAD	SP
	MOV	B,H
	MOV	C,L
	LXI	H,000AH
	DAD	D
	CALL	TR2
	SPHL
FOR10:	LHLD	FOBJ
	XCHG
	JMP	ENDL
;
NEXT:	CALL	TSTV
	JC	ERWHT
	SHLD	NCNTR
NEXT1:	PUSH	D
	XCHG
	LHLD	FCNTR
	MOV	A,H
	ORA	L
	JZ	ERWT1
	CALL	COMPR
	JZ	NEXT2
	POP	D
	CALL	POPV
	LHLD	NCNTR
	JMP	NEXT1
NEXT2:	MOV	E,M
	INX	H
	MOV	D,M
	LHLD	FSTPV
	PUSH	H
	DAD	D
	XCHG
	LHLD	FCNTR
	MOV	M,E
	INX	H
	MOV	M,D
	LHLD	FTOV
	POP	PSW
	ORA	A
	JP	NEXT4
	XCHG
NEXT4:	CALL	CMINT
	POP	D
	JC	NEXT5
	LHLD	FLABL
	SHLD	CLABL
	LHLD	FOBJ
	XCHG
	JMP	ENDL
NEXT5:	CALL	POPV
	JMP	ENDL
;
PSHV:	LXI	H,TMSTK
	CALL	TWSCP
	POP	B
	DAD	SP
	JNC	ERSRY
	LHLD	FCNTR
	MOV	A,H
	ORA	L
	JZ	NPSH
	LHLD	FOBJ
	PUSH	H
	LHLD	FLABL
	PUSH	H
	LHLD	FTOV
	PUSH	H
	LHLD	FSTPV
	PUSH	H
	LHLD	FCNTR
NPSH:	PUSH	H
	PUSH	B
	RET
;
POPV:	POP	B
	POP	H
	SHLD	FCNTR
	MOV	A,H 
	ORA	L
	JZ	NPOP
	POP	H
	SHLD	FSTPV
	POP	H
	SHLD	FTOV
	POP	H
	SHLD	FLABL
	POP	H
	SHLD	FOBJ
NPOP:	PUSH	B
	RET
;
IFSTM:	CALL	EEXPR
	MOV	A,H
	ORA	L
	JNZ	NXTGO
REM:	LXI	H,0000H
	CALL	SKPL2
	JNC	RUN2
	JMP	START
;
LIST:	CALL	GINT
	CALL	TSCR2
	CALL	SRCH
LISTL:	JC	START
	CALL	WLINE
	CALL	BREAK
	CALL	SRCH1
	JMP	LISTL
;
WLINE:	LDAX	D
	MOV	L,A
	INX	D
	LDAX	D
	MOV	H,A
	INX	D
	MVI	C,04H
	CALL	WINT
	MVI	A,' '
	CALL	PUT
	SUB	A
	CALL	MSG
	RET
;
PRINT:	MVI	C,6
PRSC:	TST	';',PRCR
	CALL	CRLF
	JMP	NXTGO
PRCR:	TST	0DH,PRSHA
	CALL	CRLF
	JMP	RUN1
PRSHA:	TST	'#',PRLTR
	CALL	EEXPR
	MOV	C,L
	JMP	PRCMA
PRLTR:	CALL	PRSUB
	JMP	PREXP
PRCMA:	TST	',',PREND
	CALL	TSTSC
	JMP	PRSHA
PREND:	CALL	CRLF
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

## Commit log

2018-10-07 KiCADデータ等整備
    [Z80-1MSRAM-2018-09-24-19-10-02.sch, Z80-1MSRAM-2018-09-30-15-57-27.sch, Z80-1MSRAM-2018-09-30-17-13-06.sch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]
2018-10-07 git無視ファイル追加
2018-10-21 機械語モニタ+TinyBASIC アドレス変更版ソース追加
2018-10-22 電源部へコンデンサ追加&パターン調整
    [Z80-1MSRAM.kicad_pcb, Z80-1MSRAM.sch]
2018-11-18 Rev1.1パターン見直し
    [Z80-1MSRAM.kicad_pcb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]
2018-11-18 回路図更新
    [Z80-1MSRAM.sch]
2018-11-18 部品表更新
    [Z80-1MSRAM.ods]
2018-11-18 部品表誤記修正
    [Z80-1MSRAM.ods]
2018-12-06 REV2基板対応
    [Z80-1MSRAM.dsn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]
2019-01-10 シルクパターン等整備
    [Z80-1MSRAM.kicad_pcb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]
2019-03-14 REV3 基板関係 試作バージョン
    [Z80-1MSRAM.dsn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]
2019-03-17 REV3からREV2.1へ改名 回路図 & 製造データ出力
    [Z80-1MSRAM.kicad_pcb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]
2019-03-17 旧回路図(REV2)別ファイルへ
2019-09-07 REV3 回路図、プリントパターン、ガーバーデータ
    [Z80-1MSRAM.dsn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]
2019-09-08 REV1回路図復活。REV3回路図改名
2021-03-24 REV4基板 ガーバーデータ出力
    [Z80-1MSRAM.dsn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]
2021-03-24 REV4 基板 部品配置変更・ガーバー出力
    [Z80-1MSRAM.dsn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]
2021-03-25 基板パターン 縁から離す対応・ガーバー出力
    [Z80-1MSRAM.dsn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]
2021-03-25 パターン微調整
    [Z80-1MSRAM.kicad_pcb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]
